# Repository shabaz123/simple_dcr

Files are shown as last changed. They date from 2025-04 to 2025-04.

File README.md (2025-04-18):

# Simple Direct Conversion Receiver for 40m (7 MHz) Band

This project is based on https://hackaday.io/project/190327/files

The main difference is that the project has been converted to a printed circuit board layout.

# Ordering

To order a PCB, [Click here for the PCB Gerber Zip File](https://github.com/shabaz123/simple_dcr/raw/main/gerber-export-dcr-pcbver-rev1_0.zip) and then upload it to any PCB manufacturer. The board is 2-layer, 160 x 100 mm in size.

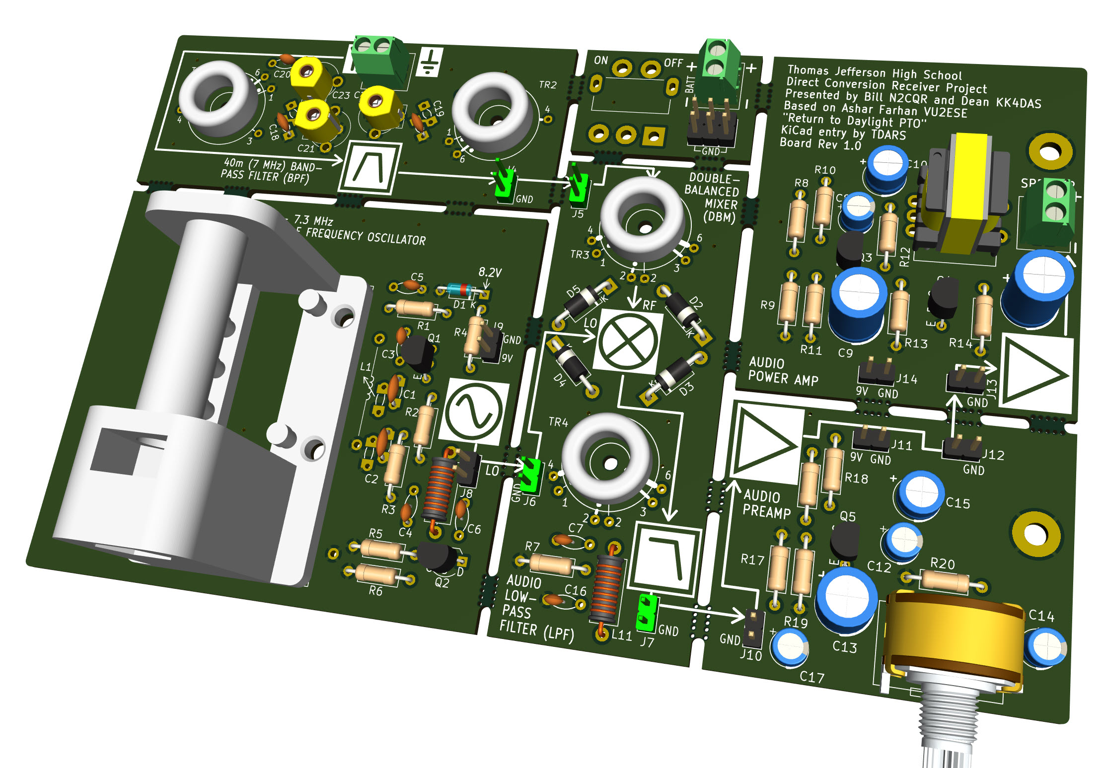
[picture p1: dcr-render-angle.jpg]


The 3D-print file for constructing the variable inductor is available from the Hackaday website [(direct link to the file)](https://cdn.hackaday.io/files/1903278142950368/PTO%20Former%20-%20print%20at%20110%20pct.stl).

The parts list is in a table further below.

# Circuit Diagram

[Click here for the PDF version](https://github.com/shabaz123/simple_dcr/raw/main/dcr-schematic-rev1_0.pdf)

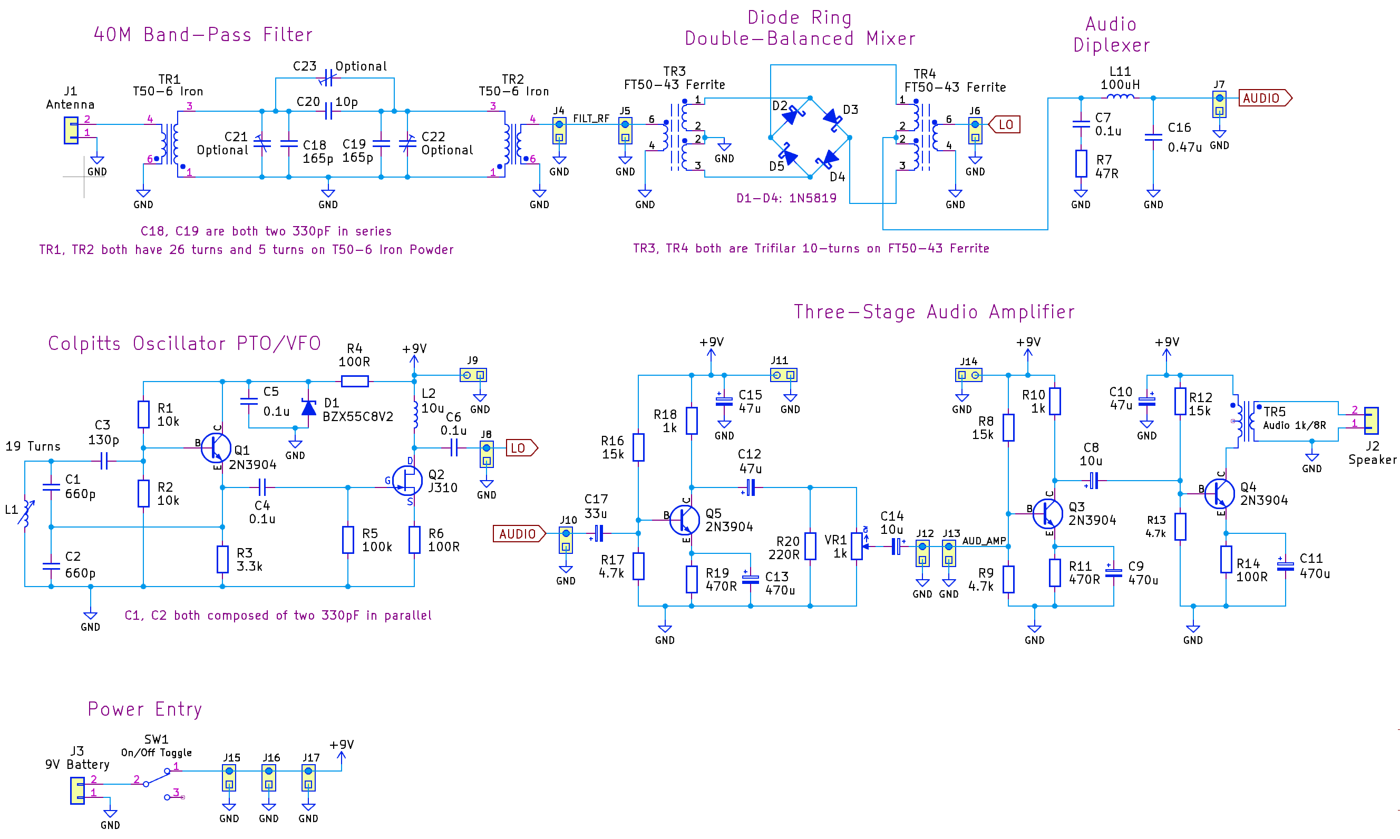
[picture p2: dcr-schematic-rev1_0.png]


# Board Layout

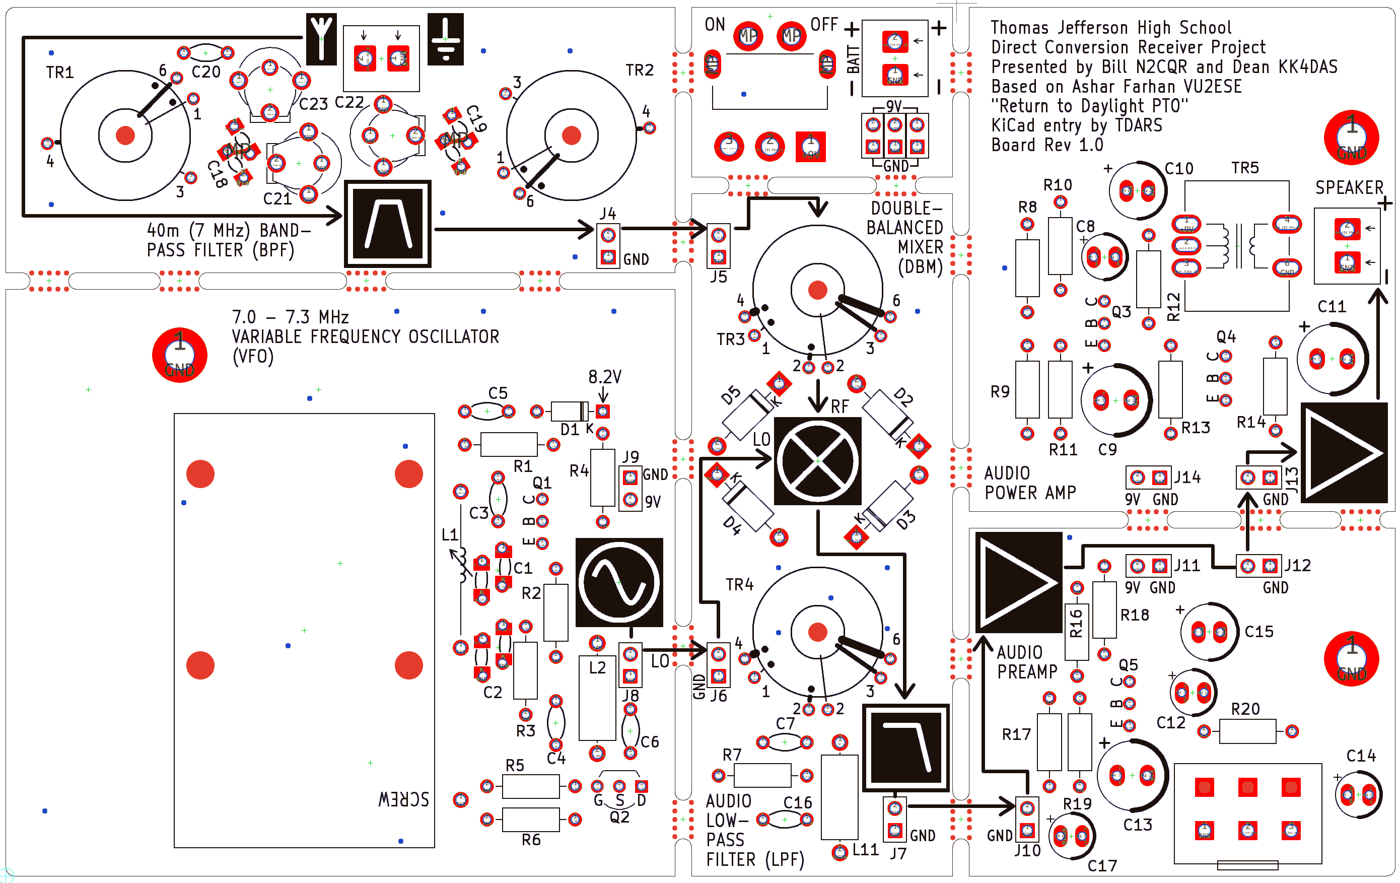
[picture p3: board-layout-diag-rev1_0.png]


## Board Underside

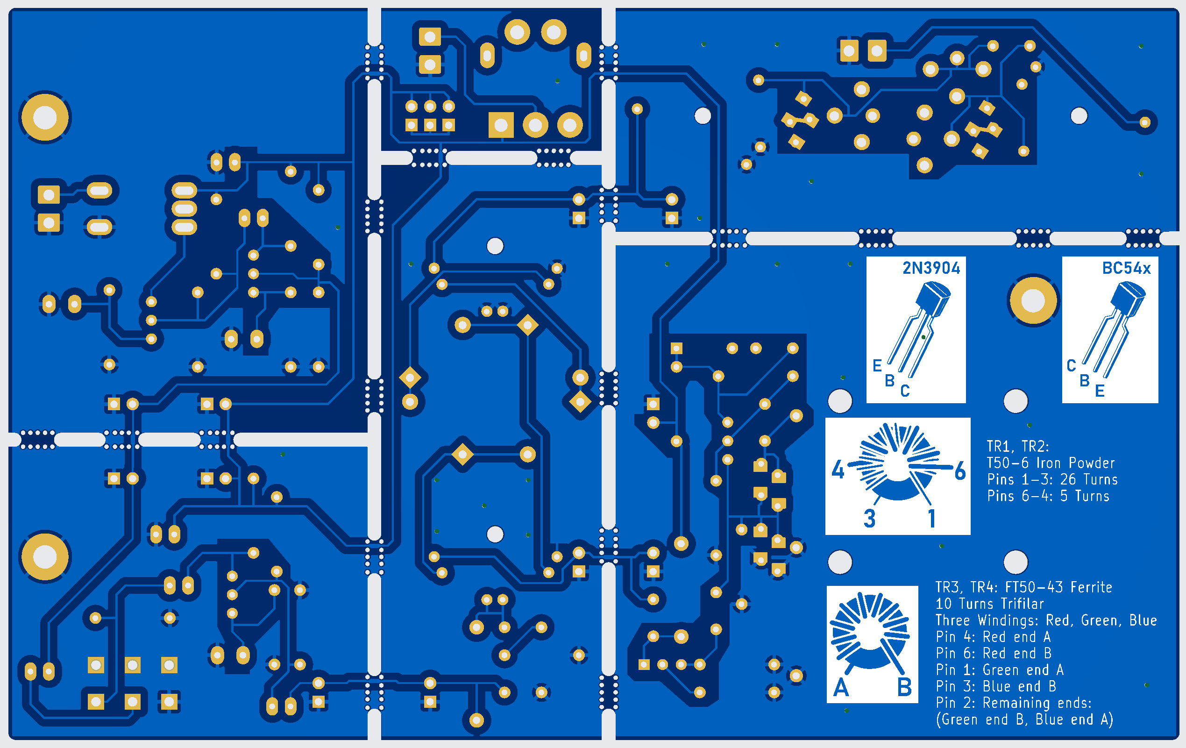
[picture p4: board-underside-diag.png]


# Toroid Detail

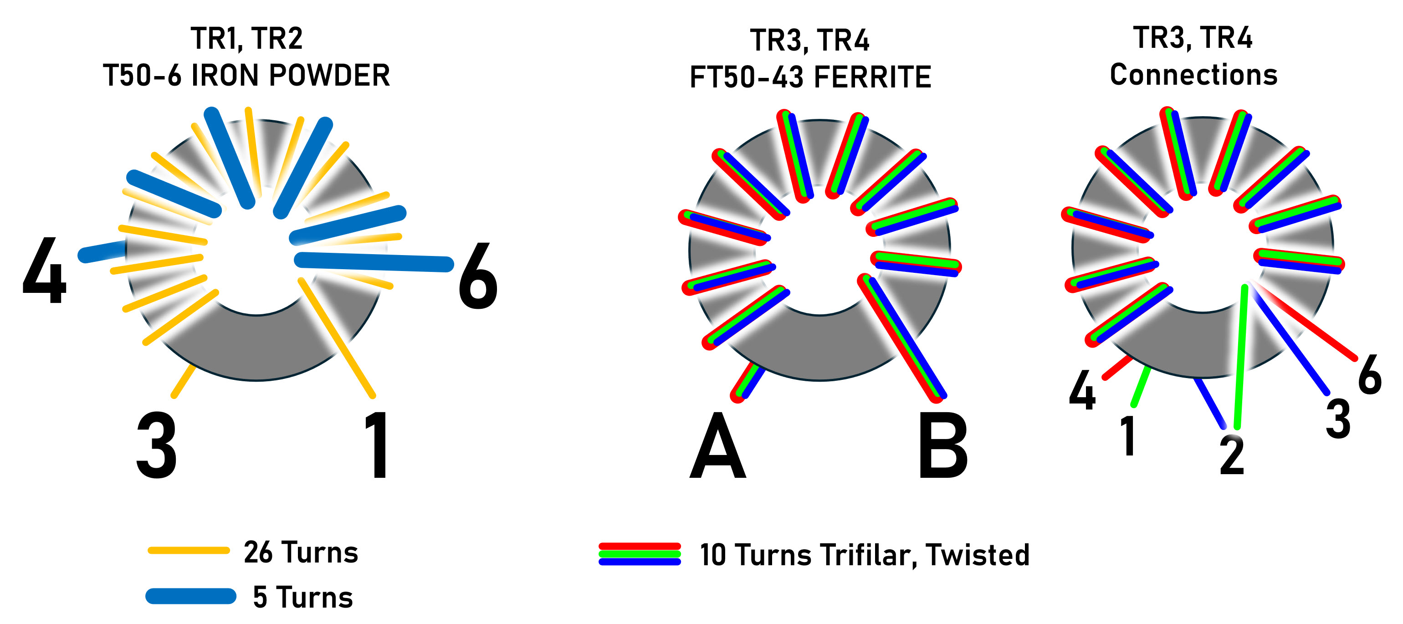
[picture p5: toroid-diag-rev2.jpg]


## TR1, TR2

T50-6 Iron Powder

Pins 1-2: 26 Turns

Pins 6-4: 5 Turns

## TR3, TR4:

FT50-43 Ferrite

10 Turns Trifilar

Three Windings: Red, Green, Blue

Pin 4: Red end A

Pin 6: Red end B

Pin 1: Green end A

Pin 3: Blue end B

Pin 2: Remaining ends (Green end B, Blue end A)

# Parts List

**Reference**|**Value**|**Qty**|**Description**
-----|-----|-----|-----
C1,C2|2 x 330pF in Parallel|4|NP0 Ceramic Capacitors (660pF combined)
C3|130p|1|NP0 Ceramic Capacitor
C4,C5,C6,C7|0.1u|4|Ceramic Capacitor
C8,C14|10u|2|Electrolytic Capacitor
C9,C11,C13|470u|3|Electrolytic Capacitor
C10,C12,C15|47u|2|Electrolytic Capacitor
C16|0.47u|1|Ceramic Capacitor
C17|33u|1|Electrolytic Capacitor
C18,C19|2 x 330pF in Series|4|NP0 Ceramic Capacitors (165pF combined)
C20|10p|1|NP0 Ceramic Capacitor
C21,C22,C23|Optional|3|40pF Trimmer Capacitors
D1|BZX55C8V2|1|Zener Diode 8.2V
D2,D3,D4,D5|1N5819|4|Schottky Diode
J1|Antenna|1|3.5mm or 3.8mm 2-way Screw Terminal Block
J2|Speaker|1|8 ohm Speaker
J3|9V Battery|1|PP3 Battery Connector
L1|Variable Inductor|1|19 Turns on 3D-printed Former
L2|10u|1|Axial Inductor
L11|100uH|1|Axial Inductor
Q1,Q3,Q4,Q5|2N3904|4|NPN Transistor
Q2|J310|1|N-ch JFET
R1,R2|10k|2|Resistor
R3|3.3k|1|Resistor
R4,R6,R14|100R|3|Resistor
R5|100k|1|Resistor
R7|47R|1|Resistor
R8,R12,R16|15k|3|Resistor
R9,R13,R17|4.7k|3|Resistor
R10,R18|1k|2|Resistor
R11,R19|470R|2|Resistor
R20|220R|1|Resistor
SW1|SPDT|1|Right-Angle SPDT Toggle Switch
TR1,TR2|T50-6|2|Toroid Iron Powder Type 6
TR3,TR4|FT50-43|2|Toroid Ferrite Type 43
TR5|Transformer 1k/8R|1|Audio Transformer 1kohm:8ohm
VR1|1k|1|Potentiometer Log Audio (Type A)
n/a|Former|1|3D-printed Coil Former for Inductor
n/a|M6 Bolt BRASS|1|M6 75 or 80 mm Screw MUST be SOLID BRASS
n/a|M6 Nut|1|M6 Nut Ideally Brass
n/a|Enamelled Wire|1|Approx 24-26 AWG Enamelled Wire

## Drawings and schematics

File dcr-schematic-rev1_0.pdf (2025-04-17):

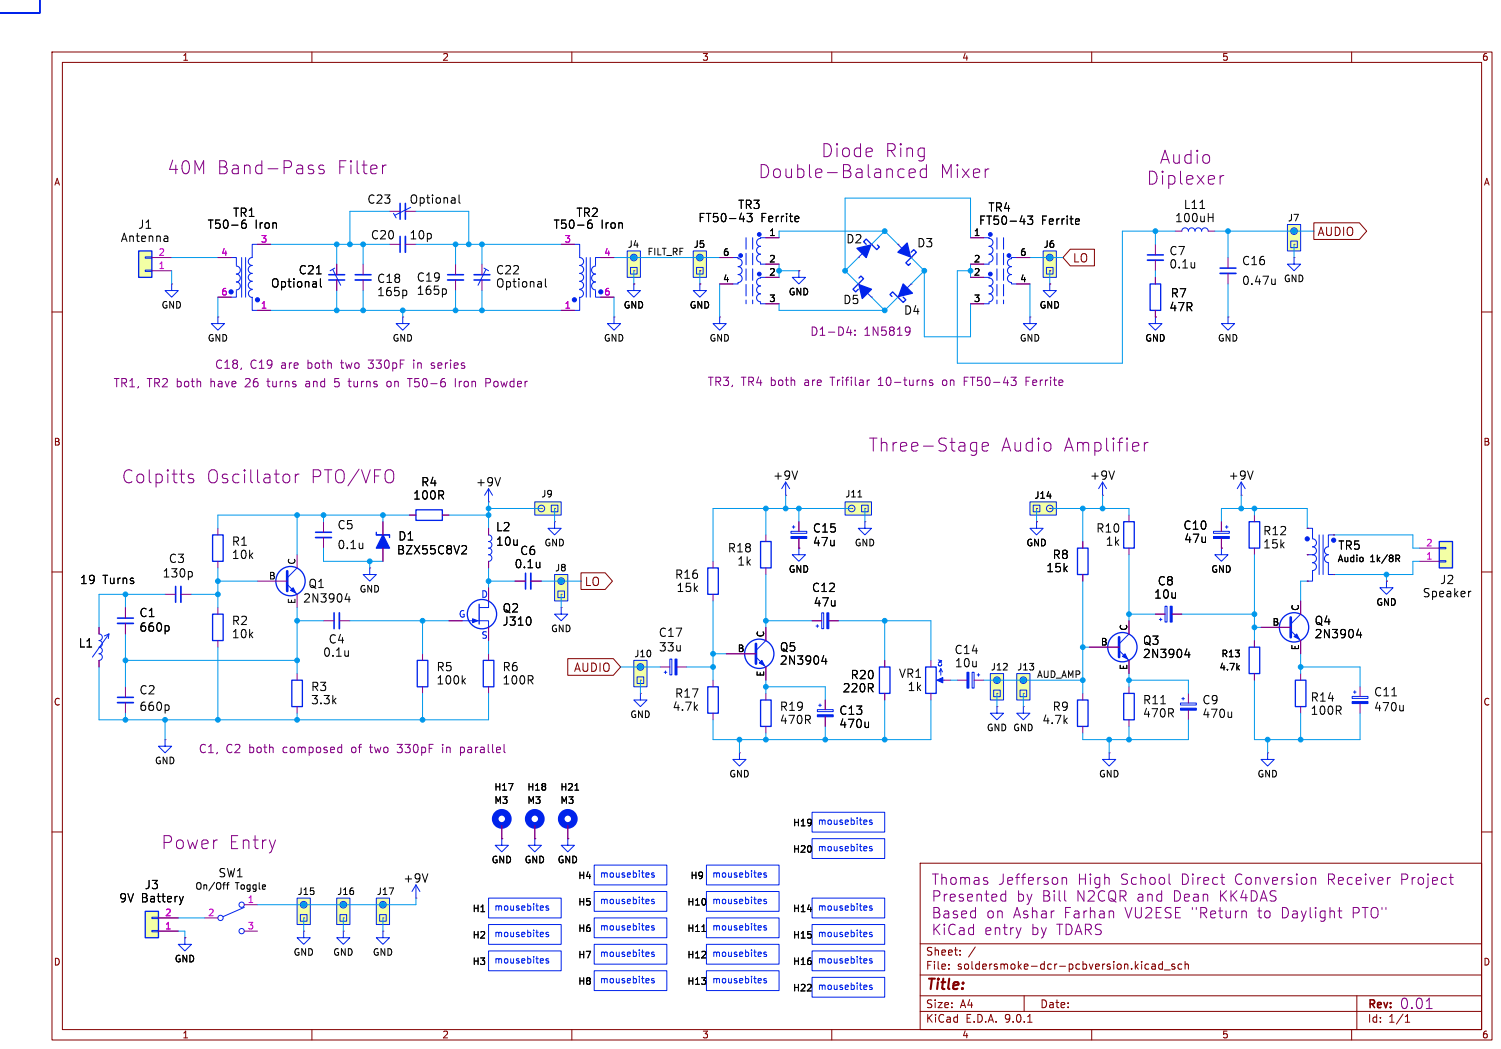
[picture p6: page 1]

GND
C18, C19 are both two 330pF in series

C1, C2 both composed of two 330pF in parallel

Thomas Jefferson High School Direct Conversion Receiver Project
Presented by Bill N2CQR and Dean KK4DAS
Based on Ashar Farhan VU2ESE "Return to Daylight PTO"
KiCad entry by TDARS

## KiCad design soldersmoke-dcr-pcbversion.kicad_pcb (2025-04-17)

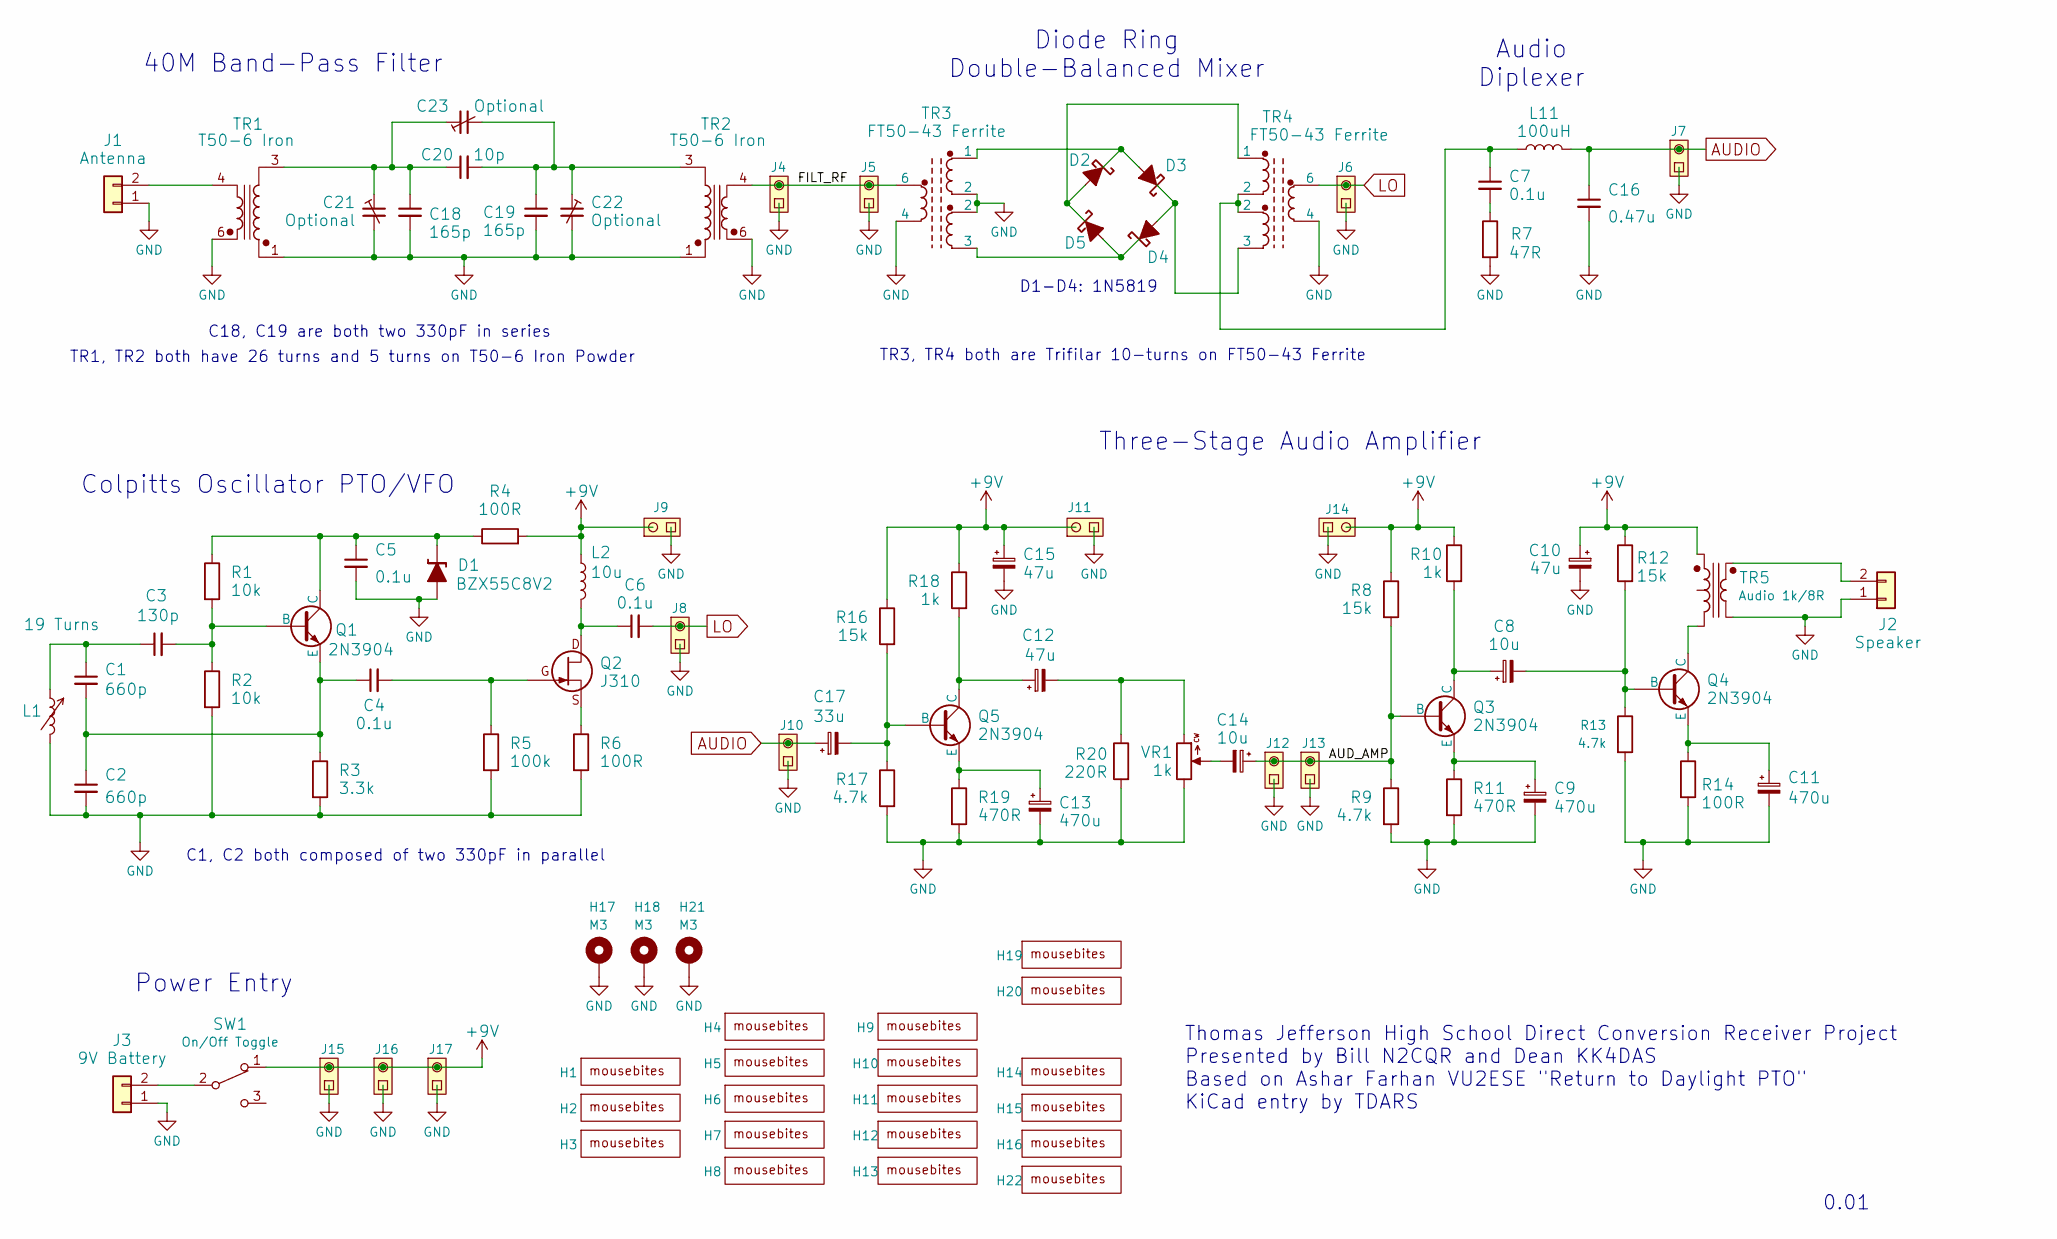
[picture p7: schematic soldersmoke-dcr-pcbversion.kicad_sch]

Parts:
C1, C2: 660p; C_Disc_Parallel_plus_1206_SMD_D3.0mm_W1.6mm_P5.0
C3: 130p; C_Disc_D3.0mm_W1.6mm_P5.0
C4, C5, C6, C7: 0.1u; C_Disc_D3.0mm_W1.6mm_P5.0
C8, C14: 10u; CP_Radial_D5.0mm_P2.50mm
C9, C11, C13: 470u; CP_Radial_D8mm_P3.5mm
C10, C15: 47u; CP_Radial_D6.3mm_P2.50mm
C12: 47u; CP_Radial_D5.0mm_P2.50mm
C16: 0.47u; C_Disc_D3.0mm_W1.6mm_P5.0
C17: 33u; CP_Radial_D5.0mm_P2.50mm
C18, C19: 165p; C_Disc_Series_plus_1206_SMD_D3.0mm_W1.6mm_P5.0
C20: 10p; C_Disc_D3.0mm_W1.6mm_P5.0
C21, C22, C23: Optional; C_Trim_Multisized
D1: BZX55C8V2; D_DO-35_SOD27_P7.62mm_Horizontal
D2, D3, D4, D5: 1N5819; D_DO-41_SOD81_P10.16mm_Horizontal_soldersmoke
H1, H2, H4, H5, H8, H10, H12, H13, H16, H20: mousebites-imperial-5-trackgap
H3, H6, H7, H9, H11, H14, H15, H19, H22: mousebites-imperial-5
H17, H18, H21: M3; MountingHole_3.2mm_M3_Pad
J1: Antenna; TerminalBlock_2way-3.5-3.81mm
J2: Speaker; TerminalBlock_2way-3.5-3.81mm
J3: 9V Battery; TerminalBlock_2way-3.5-3.81mm
J4, J5, J6, J7, J8, J9, J10, J11, J12, J13, J14, J15, J16, J17: PinHeader_1x02_P2.54mm_Vertical
L1: 19 Turns; variable-inductor-soldersmoke
L2: 10u; L_Axial_L9.5mm_D4.0mm_P12.70mm_Horizontal_Fastron_SMCC
L11: 100uH; L_Axial_L9.5mm_D4.0mm_P12.70mm_Horizontal_Fastron_SMCC
Q1, Q3, Q4, Q5: 2N3904; TO-92-soldersmoke
Q2: J310; TO-92-JFET-soldersmoke
R1, R2: 10k; R_Axial_DIN0207_L6.3mm_D2.5mm_P10.16mm_Horizontal
R3: 3.3k; R_Axial_DIN0207_L6.3mm_D2.5mm_P10.16mm_Horizontal
R4, R6, R14: 100R; R_Axial_DIN0207_L6.3mm_D2.5mm_P10.16mm_Horizontal
R5: 100k; R_Axial_DIN0207_L6.3mm_D2.5mm_P10.16mm_Horizontal
R7: 47R; R_Axial_DIN0207_L6.3mm_D2.5mm_P10.16mm_Horizontal
R8, R12, R16: 15k; R_Axial_DIN0207_L6.3mm_D2.5mm_P10.16mm_Horizontal
R9, R13, R17: 4.7k; R_Axial_DIN0207_L6.3mm_D2.5mm_P10.16mm_Horizontal
R10, R18: 1k; R_Axial_DIN0207_L6.3mm_D2.5mm_P10.16mm_Horizontal
R11, R19: 470R; R_Axial_DIN0207_L6.3mm_D2.5mm_P10.16mm_Horizontal
R20: 220R; R_Axial_DIN0207_L6.3mm_D2.5mm_P10.16mm_Horizontal
SW1: On/Off Toggle; SPDT-RA
TR1, TR2: T50-6 Iron; soldersmoke-toroid-ferrite-12.7
TR3, TR4: FT50-43 Ferrite; soldersmoke-toroid-CT-12.7
TR5: Audio 1k/8R; soldersmoke-audio-transformer
VR1: 1k; Potentiometer_soldersmoke

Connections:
+9V: C10.1, C15.1, J9.2, J11.2, J14.2, J15.2, J16.2, J17.2, L2.1, R4.2, R8.1, R10.1, R12.1, R16.1, R18.1, SW1.1 (A), TR5.1
/AUD_AMP: C14.1, J12.2, J13.2, Q3.2 (B), R8.2, R9.1
/FILT_RF: J4.2, J5.2, TR2.4, TR3.6
AUDIO: C16.1, C17.1, J7.2, J10.2, L11.2
GND: C2.2, C5.2, C9.2, C10.2, C11.2, C13.2, C15.2, C16.2, C18.2, C19.2, C21.1, C22.1, D1.2 (A), H17.1, H18.1, H21.1, J1.1, J2.1, J3.1, J4.1, J5.1, J6.1, J7.1, J8.1, J9.1, J10.1, J11.1, J12.1, J13.1, J14.1, J15.1, J16.1, J17.1, L1.1, R2.2, R3.2, R5.2, R6.2, R7.2, R9.2, R11.2, R13.2, R14.2, R17.2, R19.2, R20.2, TR1.1, TR1.6, TR2.1, TR2.6, TR3.2, TR3.4, TR4.4, TR5.6, VR1.1
LO: C6.2, J6.2, J8.2, TR4.6
unnamed: C1.1, C3.1, L1.2
unnamed: C7.1, L11.1, TR4.2
unnamed: C7.2, R7.1
unnamed: C12.2, R20.1, VR1.3
unnamed: C14.2, VR1.2
unnamed: C18.1, C20.1, C21.2, C23.2, TR1.3
unnamed: C19.1, C20.2, C22.2, C23.1, TR2.3
unnamed: C5.1, D1.1 (K), Q1.3 (C), R1.1, R4.1
unnamed: D2.2 (A), D5.1 (K), TR4.1
unnamed: D2.1 (K), D3.2 (A), TR3.1
unnamed: D3.1 (K), D4.2 (A), TR4.3
unnamed: D4.1 (K), D5.2 (A), TR3.3
unnamed: J1.2, TR1.4
unnamed: J2.2, TR5.4
unnamed: J3.2, SW1.2 (B)
unnamed: C3.2, Q1.2 (B), R1.2, R2.1
unnamed: C1.2, C2.1, C4.1, Q1.1 (E), R3.1
unnamed: C6.1, L2.2, Q2.1 (D)
unnamed: C4.2, Q2.3 (G), R5.1
unnamed: Q2.2 (S), R6.1
unnamed: C8.1, Q3.3 (C), R10.2
unnamed: C9.1, Q3.1 (E), R11.1
unnamed: C8.2, Q4.2 (B), R12.2, R13.1
unnamed: Q4.3 (C), TR5.3
unnamed: C11.1, Q4.1 (E), R14.1
unnamed: C17.2, Q5.2 (B), R16.2, R17.1
unnamed: C12.1, Q5.3 (C), R18.2
unnamed: C13.1, Q5.1 (E), R19.1

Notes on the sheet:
Audio Diplexer
Thomas Jefferson High School Direct Conversion Receiver Project Presented by Bill N2CQR and Dean KK4DAS Based on Ashar Farhan VU2ESE "Return to Daylight PTO" KiCad entry by TDARS
Colpitts Oscillator PTO/VFO
Three-Stage Audio Amplifier
Power Entry
C1, C2 both composed of two 330pF in parallel
Diode Ring Double-Balanced Mixer
40M Band-Pass Filter
C18, C19 are both two 330pF in series
TR3, TR4 both are Trifilar 10-turns on FT50-43 Ferrite
TR1, TR2 both have 26 turns and 5 turns on T50-6 Iron Powder
0.01
D1-D4: 1N5819

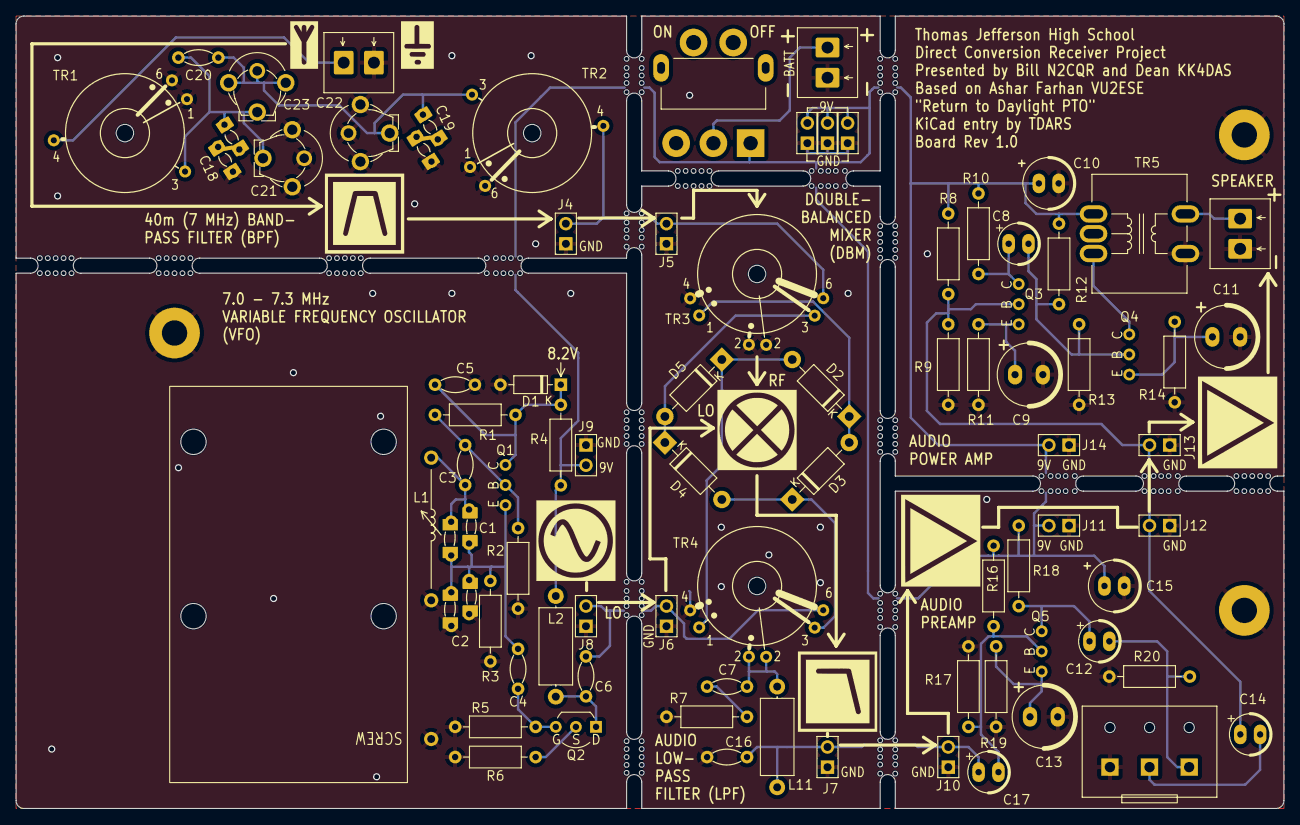
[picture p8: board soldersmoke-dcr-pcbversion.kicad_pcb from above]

Board: 2 copper layers, 160.0 x 100.0 mm, 101 parts (0 on the bottom side), 34 nets.
